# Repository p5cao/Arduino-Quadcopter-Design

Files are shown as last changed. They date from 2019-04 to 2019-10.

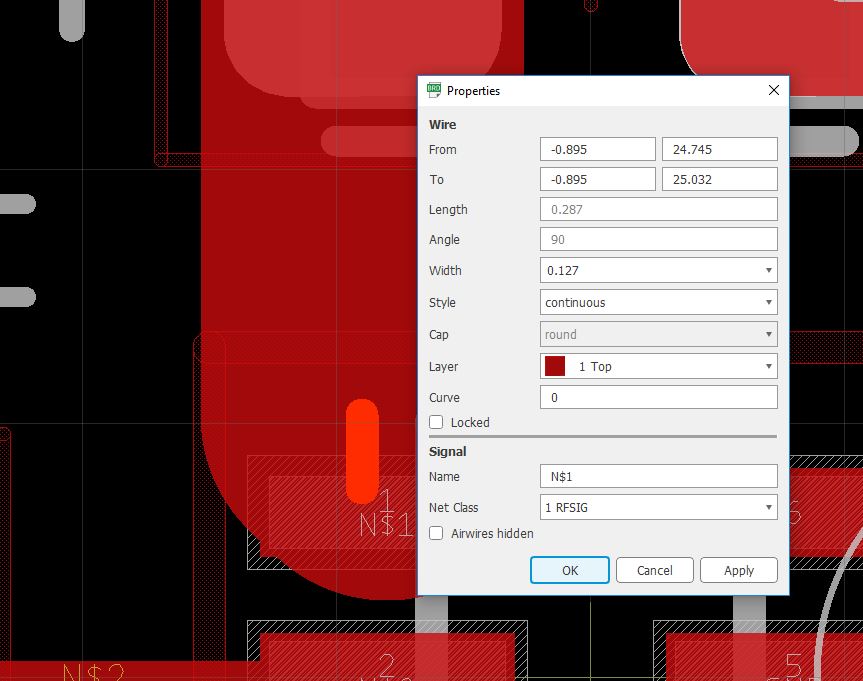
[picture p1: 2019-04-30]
hardware/N$1.JPG

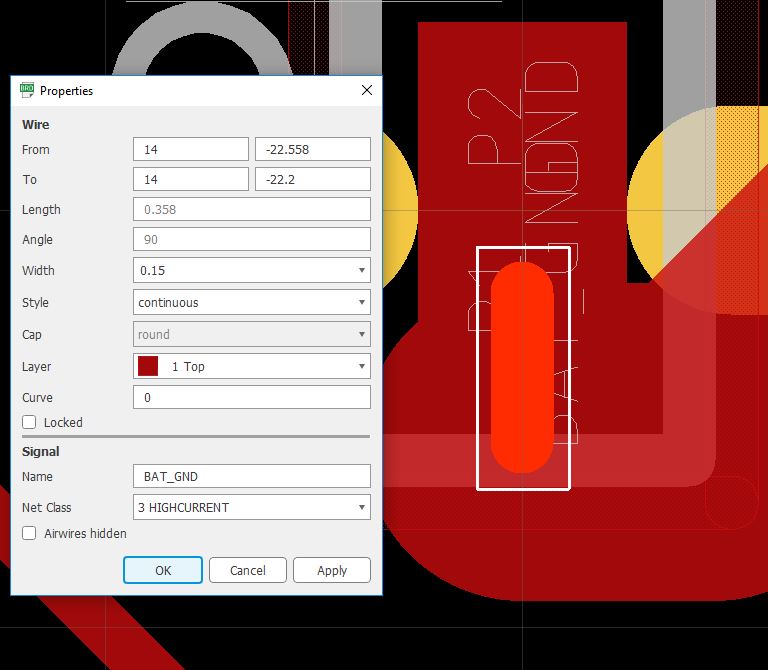
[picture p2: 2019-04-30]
hardware/bat_gnd.JPG

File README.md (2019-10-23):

# Arduino-Quadcopter-Design
A creative class project to design the PCB board for a quadcopter as well as programming the firmware and implementing the PID controller for flight controls.
The picture of our quadcopter can be found on this gallery webpage.
https://photos.google.com/share/AF1QipN9F1jDYG9cubRXA-CwWNmIePdVq3RI0pVtxd35Kb-5K7d3aRKYkmTJEXwJQgeCqA/photo/AF1QipMYG6V8wfTyHqf-2jjKtqaBbs2ouibxToXAU-El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

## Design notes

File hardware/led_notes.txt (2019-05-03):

CSE-276e 
Team KillersQuad
Members:Pengcheng Cao, Yangsheng Hu

OVERVIEW: 
18 LED lights in total will be used on the board -- 13 on the top and 5 on the bottom. Note that we are not including the two indicator LEDs (1 red and 1 green) near the MCU in this note.

---------------------------------------------------------------------------------------------------------------------------------------
Color        expected max current          forward voltages          max Supply voltages                   resistor values 
---------------------------------------------------------------------------------------------------------------------------------------
Red	25 mA			2 V		       4.2 V			88 Ohm (86.6 Ohm used)
---------------------------------------------------------------------------------------------------------------------------------------
Yellow 	25 mA			2 V		       4.2 V			88 Ohm (86.6 Ohm used)
---------------------------------------------------------------------------------------------------------------------------------------
Blue	25 mA			3.5 V	 	       4.2 V			28 Ohm
---------------------------------------------------------------------------------------------------------------------------------------

Trace width: 5mil (0.127 mm, same as our default trace setting) used.

%%%%%%%%%%%%%%%%%%%%%%%%%%%%%%%%%%%%%%%%%%%%%%%%%%%%%%%%%%%%%%%%%%%%%%%%%
%%%%%%%%%%%%%%%%%%%%%%%%%%%%%%%%%%%%%%%%%%%%%%%%%%%%%%%%%%%%%%%%%%%%%%%%%
DETAILS:

For width 0.127 mm (5 mil, same as our default trace setting), thickness 1 oz/ft^2, temperature 25 degrees Celcius, and length 100mm, the estimated trace resistance will be 0.382 Ohms, leading to a max voltage drop 0.382 Ohms*25 mA = 0.00955 V = 0.23% of the Voltage source. 
	Ref: http://circuitcalculator.com/wordpress/2006/01/24/trace-resistance-calculator

We are choosing the LTST-C170 series of LEDs emitting red, yellow, and blue lights manufactured by LITE-ON Technology Corporation. The red, yellow, and blue LEDs are of the MFR number LTST-C170KRKT, LTST-C170KSKT, and LTST-C170TBKT respectively.  The layout of LEDs ( for X-type rotor layout) will be as follows: 

*****************************************************************************************
--On the top:
4 blues on the top left arm ----------------------------------- 4 blues on the top right arm
1 yellow on the left front of the main board---------------N/A 
1 blue and 1 red on the bottom left arm ------------------- 1 yellow and 1 red on the bottom right arm
--On the bottom:
1 blue on the top left arm ------------------------------------- 1 blue on the top right arm
1 blue on the left middle of the main board -------------- N/A
1 yellow on the bottom left arm ----------------------------- 1 yellow on the bottom right arm
*****************************************************************************************  
Note: All the LEDs on the left will be driven by one MOSFET, and the ones on the right will be driven by another MOSFET.

Roughly speaking, we are using the red LEDs (warm color) as rear lights of our quad and the blue (cold color) indicating the foward direction.  LEDs will also be added on the left hand side of the main board to give a straightforward left direction.  The 5 LEDs on the bottom will tell the outline of our quad.

The LEDs on the left are connected to the PWM pin 9~ on the microcontroller (PB4 pin) via the mosfet from our custom library, which is the Si302CDS N-Channel 20V (D-S) mosfet provided by Vishay Siliconix. The LEDs on the right are connnected to the PWM pin 34~ on the microcontroller (PB6 pin) with a similar connection through another mosfet. We connect S-gate of the mosfet to pin 9~/34~ of the microcontroller, the G-gate to BAT_GND, and D-gate to all the parallel-connected LEDs. The total 18 LEDs will consume current of 450 mA, with 25 mA allocated to each to ensure at least 1.2 relative luminous intensity at high battery voltage(4.2V) and 0.9 relative luminous intensity at low battery voltage(3.7V). Each LED has a resistor serially connected to it to restrict the currents, and the power of LEDs is provided by V_BAT. We use the Ohm's law equation R = (V_source - V_LED)/I_LED to calculate the resistance required for choosing the resistors from DigiKey. 

The red and yellow LEDs have the maximum forward current (I_LED) of 25mA at maximum supply voltage (V_source) of 4.2V, which corresponds to 1.25 relative luminous intensity and the forward voltage (V_LED) of 2V. The anticipated serial resistor to be used here will be 88 Ohm. We are choosing the YAGEO RC0805FR-0786R6L resistor with 86.6 resistance to connect to the diode. We need in total 14 resistors of this type.

The Blue LEDs also have the maximum forward current of 25mA (mapped to 1.2 relative luminous intensity on the curve), with the correspondng forward voltage of 3.5V and maximum supply voltage(V_source) of 4.2V. So based on Ohms Law we need to connect the Blue LED with a serial resistor of 28 Ohm. We shall choose to use YAGEO RC0805FR-0728RL resistor with exactly 28 Ohm resistance. We need in total 4 resistors of this type. 

All the resistors are selected from the same series, Yageo RC, as the resistor in the custom library we built before, and also share the same mounting pad sizes and footprint.

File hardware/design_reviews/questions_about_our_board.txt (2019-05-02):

Reviewer Team Name: sudo_woodo
  
Devin Moore  djm016@ucsd.edu
  Brendon Chen brc019@ucsd.edu

Reviewee Team Name: killersquad
  
Pengcheng Cao p5cao@eng.ucsd.edu
  Yangsheng Hu  yah071@eng.ucsd.edu

Met: April 30, 2019 at ~12:00 PM PT

1. IMU Decoupling Capacitors

According to Prof. Swanson, "Ideally there should be no vias between a
   decoupling cap and the device." (See Piazza post @145)

Our answer: We have connected them directly without vias in between now.

2. Under the IMU, Layer 15

What is that yellow rectangle? Is it a trace? We are not sure.

Our answer: We have also built two cutouts within the IMU package, although we've already have the cutouts directly on the board. This will not hurt.

3. MCU Decoupling Capacitors

According to Prof. Swanson, "Ideally there should be no vias between a
   decoupling cap and the device." (See Piazza post @145)

Our answer: We have connected them directly without vias in between now.

4. There are name/value labels on vias throughout the board

For example, see R18, D14, D13, ...

Our answer: We have modified this problem.

5. LEDs

Traces N$37 and N$33 seem a bit sharp (e.g., 90 degree angles)

Our answer: We have rerouted our board based on a modified version and now no problems on this.

6. DRC

There are wire stubs that should be cleaned up (e.g., RES@3:GND)

Our answer: We have cleaned unnecssary wire stubs. Only two necessary ones are left (for antenna and NET_BRIDGE).

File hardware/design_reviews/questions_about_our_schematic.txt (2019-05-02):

Reviewer Team Name: sudo_woodo
  
Devin Moore  djm016@ucsd.edu
  Brendon Chen brc019@ucsd.edu

Reviewee Team Name: killersquad
  
Pengcheng Cao p5cao@eng.ucsd.edu
  Yangsheng Hu  yah071@eng.ucsd.edu

Met: April 30, 2019 at ~12:00 PM PT

1. LED Connections

The wires between LEDs and current limiting resistors are of class default.
   As a result, they are only 5 mil (0.127 mm) wide on the board. Is that
   alright since the trace sizes connecting the LED-resistor branches to VBAT
   and NMOSFETs are 30 mil? 

Our answer: that's a mistake, and we have corrected it.

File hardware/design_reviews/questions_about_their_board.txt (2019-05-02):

Reviews for the board design (Sudo_Wodoo)
--reviewed by Yangsheng Hu and Pengcheng Cao (2019/05/01)

Reviewer Team Name: killersquad
  
Pengcheng Cao p5cao@eng.ucsd.edu
  Yangsheng Hu  yah071@eng.ucsd.edu

Reviewee Team Name: sudo_woodo
  
Devin Moore  djm016@ucsd.edu
  Brendon Chen brc019@ucsd.edu

Met: April 30, 2019 at ~12:00 PM PT

Antenna and Antenna Driver:
1. The wire connection for the antenna is right. However, mayber it's better to do an mimic placement on the board as given in the repo. More specifically,  capacitor C1 can be moved to right up to the Balun.
2. I noticed that the pours are only covering the area below the capacitor C1. In fact, you can cover C1, too. Then, the GND pad on C1 could be connected to the GND plane directly through a via or so. 
3. Since we prefer to have nothing around the RF area, then we should be careful about the signals A7, A5, A3, which are pretty close to the balun in your design.

Power and Ground:
1. Some parts of the power/ground pours are very narrow (<0.5mm). Display each layer separately and pay attention to those parts with a cross shape, usually sitting in the throughhole. For example, if you check your throughhole GND of the IMU rescue header, and display only the ground plane layer 2, then you can see that cross parts are less than 0.5mm, which is roughly 0.3mm. This happens to be your PWR net class trace width. Probably this is a bug in autorouting such that some power/ground traces may finally be part of the power/ground pours during the final steps of the pour optimization. A possible solution: reduce the traces layout for power/ground signal; instead, use a via to directly push it into a power/gound plane. By doing this, the cross connection in the throughhole will be generated using the default thick metals.
2. For the Highcurrent net class, I think you've set your via diameters too small. The drill size should give an annular ring diameter of 30mil with annular ring to be 25% of drill radius. Your drill diameter should be no smaller than 24 mil.

IMU:
1. The capacitors are lying too close to each other, this would be hard for you to drop your parts on your board. In fact, not all the capacitors are important and sensitive. So, just make sure the sensitive ones are placed as near as possible. 
2. The position of the IMU header should be refined to make sure that the IMU on the breakout board(https://www.adafruit.com/product/3387) is roughly in the center. It seems like you can move the header a little bit to the right.

Microcontroller:
1. Similar to the IMU, the capacitors arel lying too close to each other. Professor suggests to allow 1-2mm between parts to make assembly easy.

Power Supply:
1. 3V3 plane power plane is not running underneath the voltage regulator U5. Thus, it will take some distance to go from your regulated 3V3 output to your other 3V3 parts.

Mechanical:
1. The arm length (from the center of DC motor to the edge of the board is about 31mm) is O.K. but maybe too short since the radius of the propeller is 55/2=27.5mm.  
2. The direction of the battery header B2 should be taken care of since it is facing the upper left propeller, which is pretty close (I did a basic calculation which is about 12mm). You will be struggling then when you get your battery wires in.
3. For the "cup" holder, the open angle is about 90 degree, which is fine, but can be smaller for better hold. Also, maybe it's better to give a little cut inside the motor holder circle to allow a bit stretching when you are squeezing in your motors.
4. Orienting all your parts in the same direction makes assembly easier (notice this on the FCB and your remote board).

LEDs:
1. The calculation is questionable (your final computed through current is said to be 3.94mA, however, this will lead to a different forward voltage again instead of the 2.0-2.1V, which is not matching). Since the through current depends on the forward voltage, the reasonable way is: first, set your expected through current and find the corresponding forward voltage; then, basing on your forward voltage and source voltage, calculate the remaining voltage the attached resistor should undertake; finally, you will have the value of the resistor based on the remaining voltage and through current.

Checks (DRC): 
1. Why did the error "clearance" at the Net Bridge 1 not resolved? Please explain
2. Why did width error of N$5 at pin 1 of balun 1 not resolved? Please explain
3. Why did width error of BAT_GND at Net Bridge 1 not resolved? Please explain

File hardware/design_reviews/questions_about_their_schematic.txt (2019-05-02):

Reviews for the Schematic drawing (Sudo_Wodoo)
-- reviewed by Yangsheng Hu and Pengcheng Cao (2019/05/01)

Reviewer Team Name: killersquad
  
Pengcheng Cao p5cao@eng.ucsd.edu
  Yangsheng Hu  yah071@eng.ucsd.edu

Reviewee Team Name: sudo_woodo
  
Devin Moore  djm016@ucsd.edu
  Brendon Chen brc019@ucsd.edu

Section I: Power supply

1. you should use the provided VBAT symbol instead of define a VBAT label on you net conected to enable pin.

2. try not to divide your schematic into too many components.

Section II: Headers

1. Think maybe you could specify your two headers by telling reader which one is IMU rescue or connects to signal pins.

2. Again you should try to symbols provided like VBAT, BAT_GND instead of defining labels.

Section III: LEDs

1. Your LED symbols may be too big, the professor has suggested to make the symbols no bigger than size of 0.4 x 0.2 inch, which produces inconsistency between professor's LED symbols and yours.  

Section IV: Motor Drivers

1. Think you should mark you Schottky diodes with a "Flyback" dashed box.

Section V: IMU

1. Your IMU symbol may be problematic. You should only place power pins at the top and ground pins at the bottom.  Dont treat C1 and CAP as Grounds they still have caps connected.

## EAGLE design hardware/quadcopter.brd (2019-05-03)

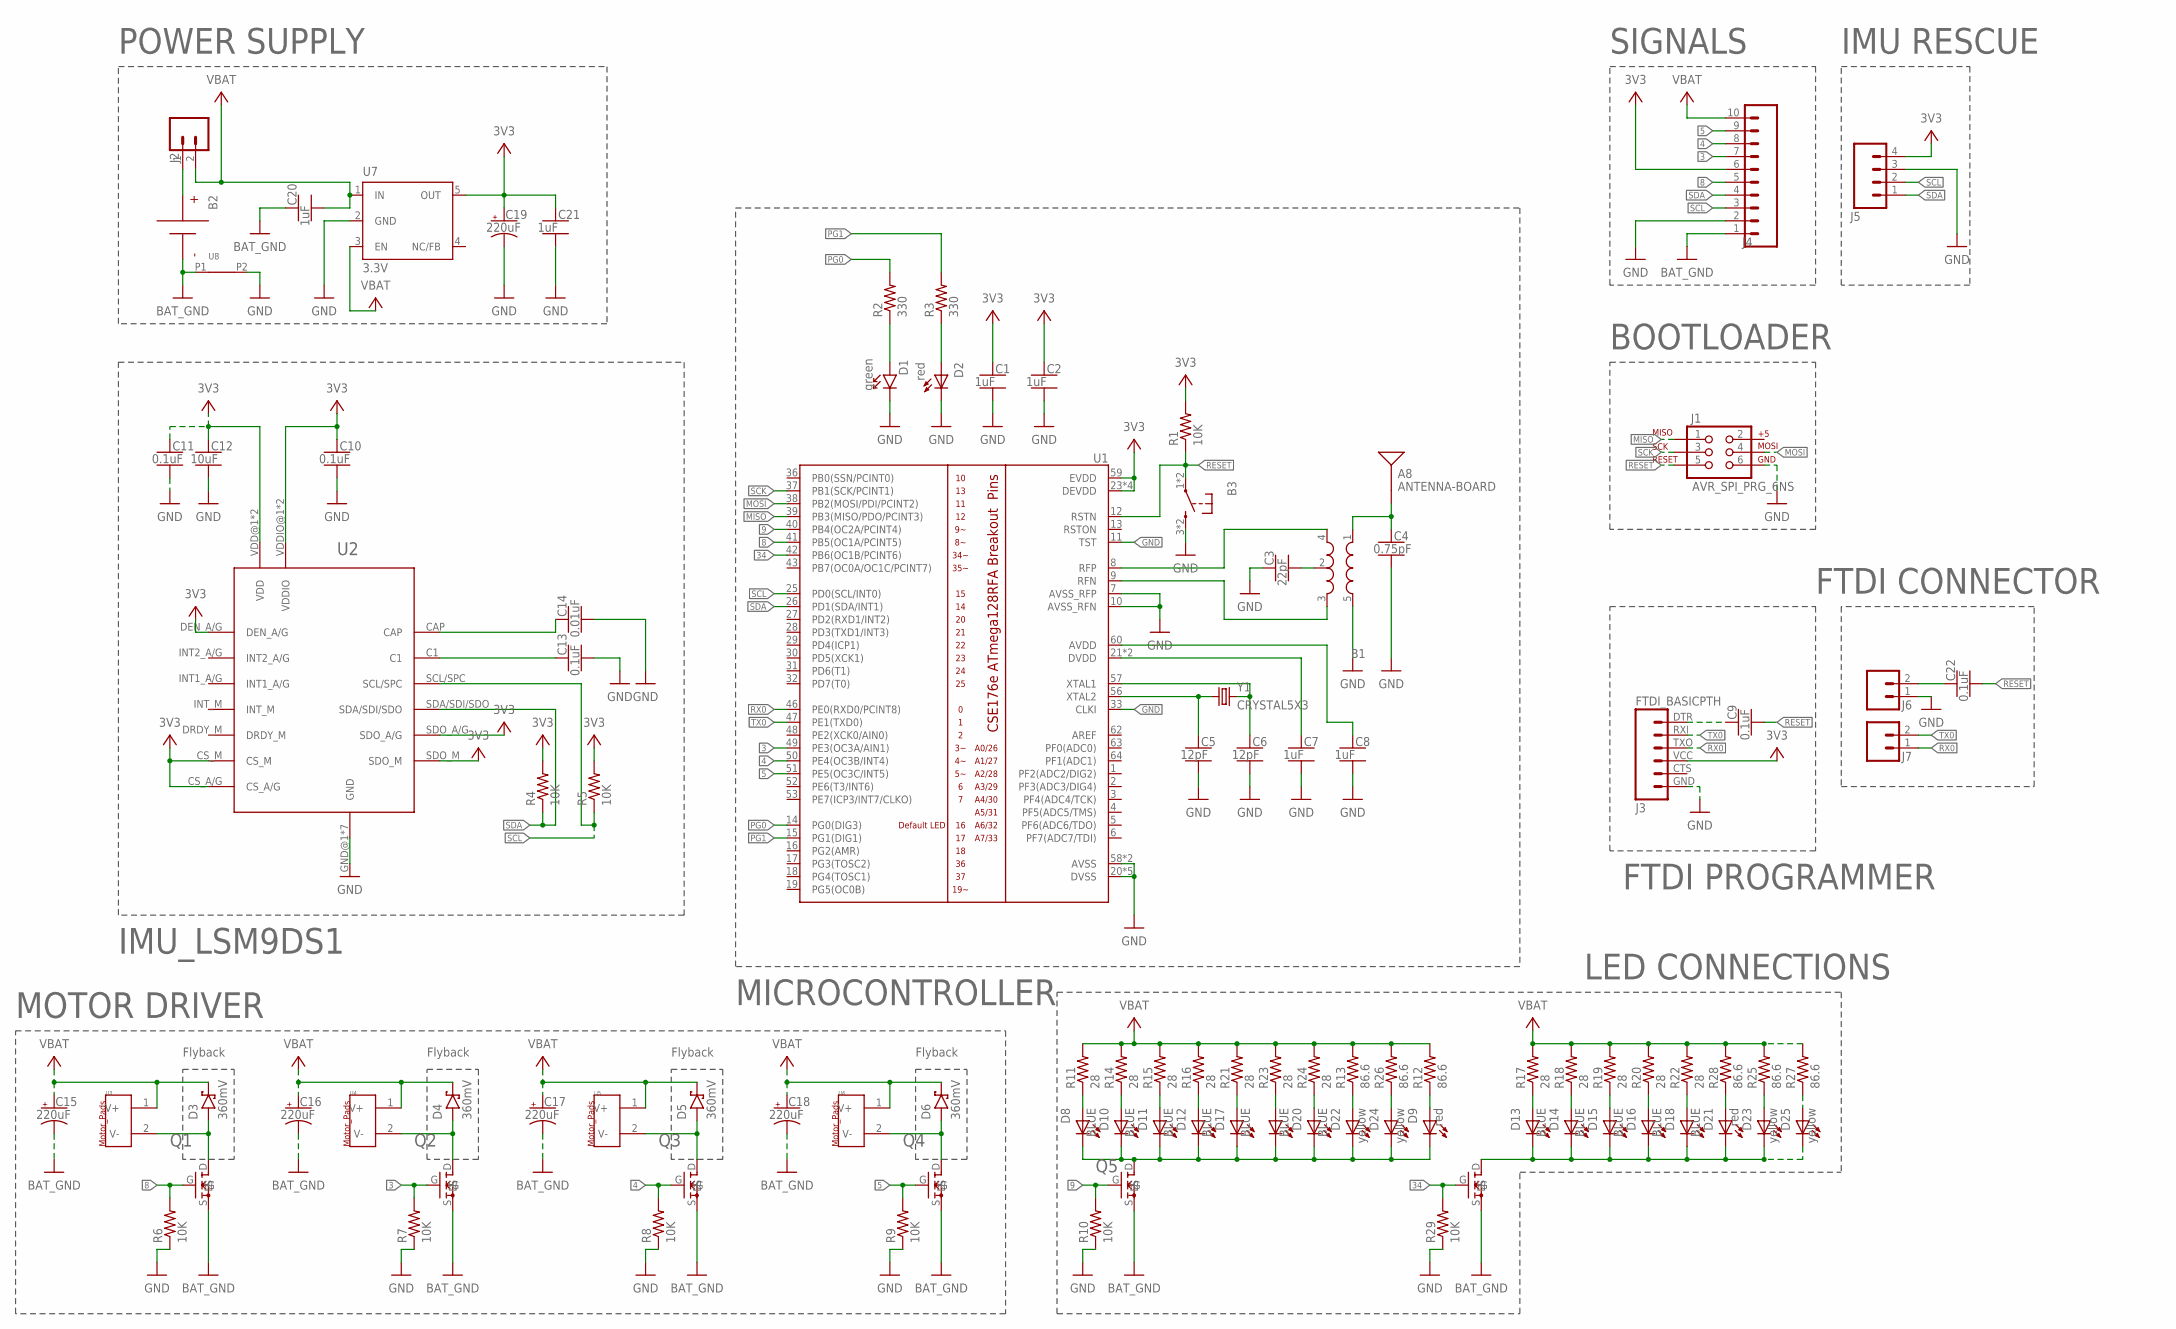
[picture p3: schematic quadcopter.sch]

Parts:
A8: ANTENNA-BOARD; ANT_PCB_2.4GHZ_NRF8001_1.6MM_1OZ
B1: BALUN0805; BALUN
B2: BATTERY-SCREW-TERMINAL; SCREW-TERMINAL-1X2-2.54MM
B3: PUSHBUTTON_-4.5X4.5; 4.5MM_TACTILE_SWITCH_TL3305AF160QG
C1, C2, C7, C8, C20, C21: 1uF; CAPC2012X140_HS
C3: 22pF; CAPC2012X140_HS
C4: 0.75pF; CAPC2012X140_HS
C5, C6: 12pF; CAPC2012X140_HS
C9, C10, C11, C13, C22: 0.1uF; CAPC2012X140_HS
C12: 10uF; CAPC2012X140_HS
C14: 0.01uF; CAPC2012X140_HS
C15, C16, C17, C18, C19: 220uF; CAPMP7343X310_HS
D1: green; LEDSC125X200X120-2_HS
D2: red; LED
D3, D4, D5, D6: 360mV; SOD3716X135_HS
D8, D10, D11, D12, D13, D14, D15, D16, D17, D18, D19, D20: BLUE; DIODE-LED-LTST-C170
D9, D21: red; DIODE-LED-LTST-C170
D22, D23, D24, D25: yellow; DIODE-LED-LTST-C170
J1: AVR_SPI_PRG_6NS; 2X3-NS
J2: HEADER-0.1IN-2POS-MALE; HDRV2W63P254_2X1_508X254H838_HS
J3: FTDI_BASICPTH; FTDI_BASIC
J4: HEADER-10POSTH-254X10; HDRV10W63P254_10X1_2540X254H838_HS
J5: HEADER-4POS-0.1IN-FEMALE; HDRVR4W80P254_1X4_1066X254X850B
J6, J7: HEADER-0.1IN-2POS-FEMALE; HDRV2W63P254_2X1_508X254H838_HS
Q1, Q2, Q3, Q4, Q5, Q6: MOSFET-VISHAY-SOT23-N-MOSFET; SOT-23_N_MOSFET
R1, R4, R5, R6, R7, R8, R9, R10, R29: 10K; RESC2012X60_HS
R2, R3: 330; RESC2012X60_HS
R11, R14, R15, R16, R17, R18, R19, R20, R21, R22, R23, R24: 28; RESC2012X60_HS
R12, R13, R25, R26, R27, R28: 86.6; RESC2012X60_HS
U1: ATMEGA128RFA1; QFN-64
U2: IMU_LSM-ST-LSM9DS1-IMU-LGA; LSM9DS1_IMU
U3, U4, U5, U6: MOTOR_PADS-MOLEX-0530470210; MOLEX-0530470210
U7: 3.3V; SOT23-DBV
U8: NET_BRIDGE-BRIDGE-SMD; NET_BRIDGE
Y1: CRYSTAL5X3; CRYSTAL-SMD-5X3

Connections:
3: J4.7, Q2.G, R7.2, U1.49 (PE3(OC3A/AIN1))
3V3: C1.1, C2.1, C10.1, C11.1, C12.1, C19.1 (+), C21.1, J3.VCC (4), J4.6, J5.4, R1.2, R4.2, R5.2, U1.23 (DEVDD), U1.34 (DEVDD), U1.44 (DEVDD), U1.54 (DEVDD), U1.59 (EVDD), U2.CS_A/G, U2.CS_M, U2.DEN_A/G, U2.SDO_A/G, U2.SDO_M, U2.VDD@1 (VDD), U2.VDD@2 (VDD), U2.VDDIO@1 (VDDIO), U2.VDDIO@2 (VDDIO), U7.5 (OUT)
4: J4.8, Q3.G, R8.2, U1.50 (PE4(OC3B/INT4))
5: J4.9, Q4.G, R9.2, U1.51 (PE5(OC3C/INT5))
8: J4.5, Q1.G, R6.2, U1.41 (PB5(OC1A/PCINT5))
9: Q5.G, R10.2, U1.40 (PB4(OC2A/PCINT4))
34: Q6.G, R29.2, U1.42 (PB6(OC1B/PCINT6))
BAT_GND: B2.1 (N), C15.2 (-), C16.2 (-), C17.2 (-), C18.2 (-), C20.1, J4.1, Q1.S, Q2.S, Q3.S, Q4.S, Q5.S, Q6.S, U8.P1
GND: B1.5 (GND), B3.3 (2), B3.4 (2), C1.2, C2.2, C3.1, C4.2, C5.2, C6.2, C7.2, C8.2, C10.2, C11.2, C12.2, C13.2, C14.2, C19.2 (-), C21.2, D1.C, D2.C, J1.6, J3.GND (6), J4.2, J5.3, J6.1, R6.1, R7.1, R8.1, R9.1, R10.1, R29.1, U1.7 (AVSS_RFP), U1.10 (AVSS_RFN), U1.11 (TST), U1.20 (DVSS), U1.24 (DVSS), U1.33 (CLKI), U1.35 (DVSS), U1.45 (DVSS), U1.55 (DVSS), U1.58 (AVSS), U1.61 (AVSS), U2.GND@1 (GND), U2.GND@2 (GND), U2.RES@1 (GND), U2.RES@2 (GND), U2.RES@3 (GND), U2.RES@4 (GND), U2.RES@5 (GND), U7.2 (GND), U8.P2
MISO: J1.1, U1.39 (PB3(MISO/PDO/PCINT3))
MOSI: J1.4, U1.38 (PB2(MOSI/PDI/PCINT2))
unnamed: A8.FEED, B1.1 (IN), C4.1
unnamed: B1.2 (GND), C3.2
unnamed: B1.4 (OUT1), U1.8 (RFP)
unnamed: B1.3 (OUT2), U1.9 (RFN)
unnamed: C5.1, U1.56 (XTAL2), Y1.1
unnamed: C6.1, U1.57 (XTAL1), Y1.3 (2)
unnamed: C7.1, U1.21 (DVDD), U1.22 (DVDD)
unnamed: C8.1, U1.60 (AVDD)
unnamed: D1.A, R2.1
unnamed: D2.A, R3.1
unnamed: C9.1, J3.DTR (1)
unnamed: C13.1, U2.C1
unnamed: C14.1, U2.CAP
unnamed: D3.A, Q1.D, U3.2 (V-)
unnamed: B2.2, J2.1
unnamed: D4.A, Q2.D, U4.2 (V-)
unnamed: D21.A, R28.1
unnamed: D5.A, Q3.D, U5.2 (V-)
unnamed: C22.1, J6.2
unnamed: D6.A, Q4.D, U6.2 (V-)
unnamed: D9.A, R12.1
unnamed: D24.A, R26.1
unnamed: D23.A, R25.1
unnamed: D22.A, R13.1
unnamed: D20.A, R24.1
unnamed: D19.A, R23.1
unnamed: D18.A, R22.1
unnamed: D17.A, R21.1
unnamed: D16.A, R20.1
unnamed: D15.A, R19.1
unnamed: D14.A, R18.1
unnamed: D13.A, R17.1
unnamed: D12.A, R16.1
unnamed: D11.A, R15.1
unnamed: D10.A, R14.1
unnamed: D8.A, R11.1
unnamed: D8.C, D9.C, D10.C, D11.C, D12.C, D17.C, D19.C, D20.C, D22.C, D24.C, Q5.D
unnamed: D13.C, D14.C, D15.C, D16.C, D18.C, D21.C, D23.C, D25.C, Q6.D
unnamed: D25.A, R27.1
PG0: R2.2, U1.14 (PG0(DIG3))
PG1: R3.2, U1.15 (PG1(DIG1))
RESET: B3.1, B3.2 (1), C9.2, C22.2, J1.5, R1.1, U1.12 (RSTN)
RX0: J3.TXO (3), J7.1, U1.46 (PE0(RXD0/PCINT8))
SCK: J1.3, U1.37 (PB1(SCK/PCINT1))
SCL: J4.3, J5.2, R5.1, U1.25 (PD0(SCL/INT0)), U2.SCL/SPC
SDA: J4.4, J5.1, R4.1, U1.26 (PD1(SDA/INT1)), U2.SDA/SDI/SDO
TX0: J3.RXI (2), J7.2, U1.47 (PE1(TXD0))
VBAT: C15.1 (+), C16.1 (+), C17.1 (+), C18.1 (+), C20.2, D3.C, D4.C, D5.C, D6.C, J2.2, J4.10, R11.2, R12.2, R13.2, R14.2, R15.2, R16.2, R17.2, R18.2, R19.2, R20.2, R21.2, R22.2, R23.2, R24.2, R25.2, R26.2, R27.2, R28.2, U3.1 (V+), U4.1 (V+), U5.1 (V+), U6.1 (V+), U7.1 (IN), U7.3 (EN)

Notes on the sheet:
MICROCONTROLLER
BOOTLOADER
FTDI PROGRAMMER
IMU_LSM9DS1
Flyback
MOTOR DRIVER
POWER SUPPLY
SIGNALS
IMU RESCUE
LED CONNECTIONS
FTDI CONNECTOR

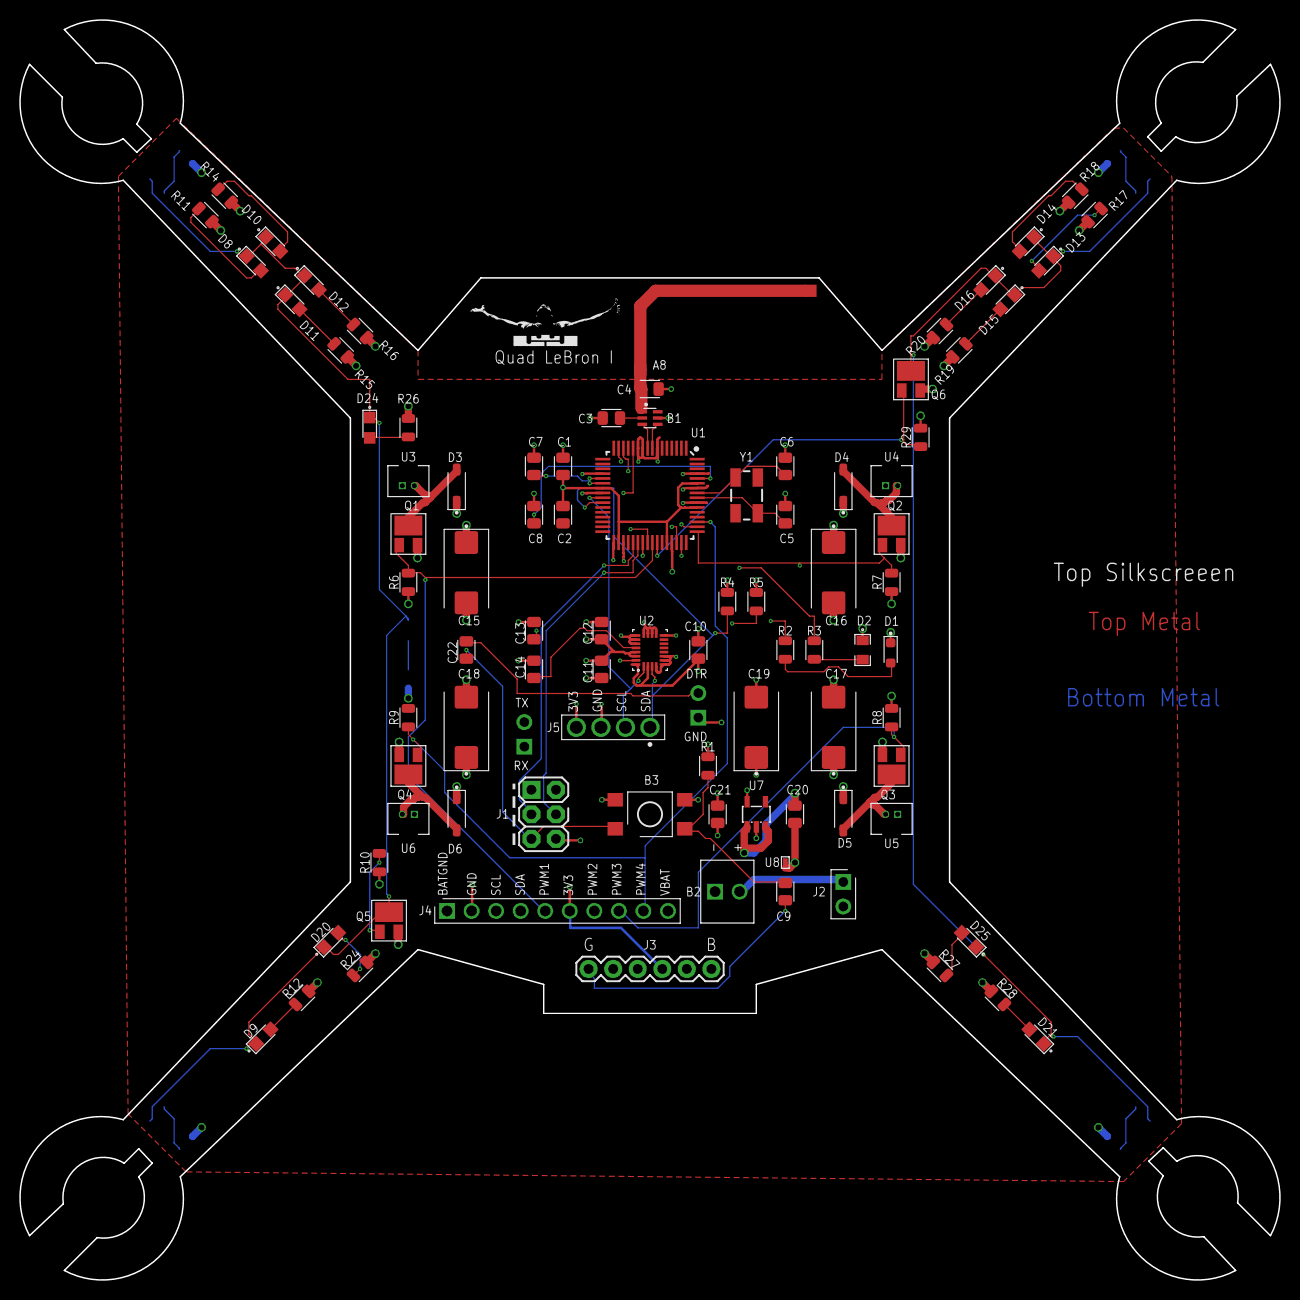
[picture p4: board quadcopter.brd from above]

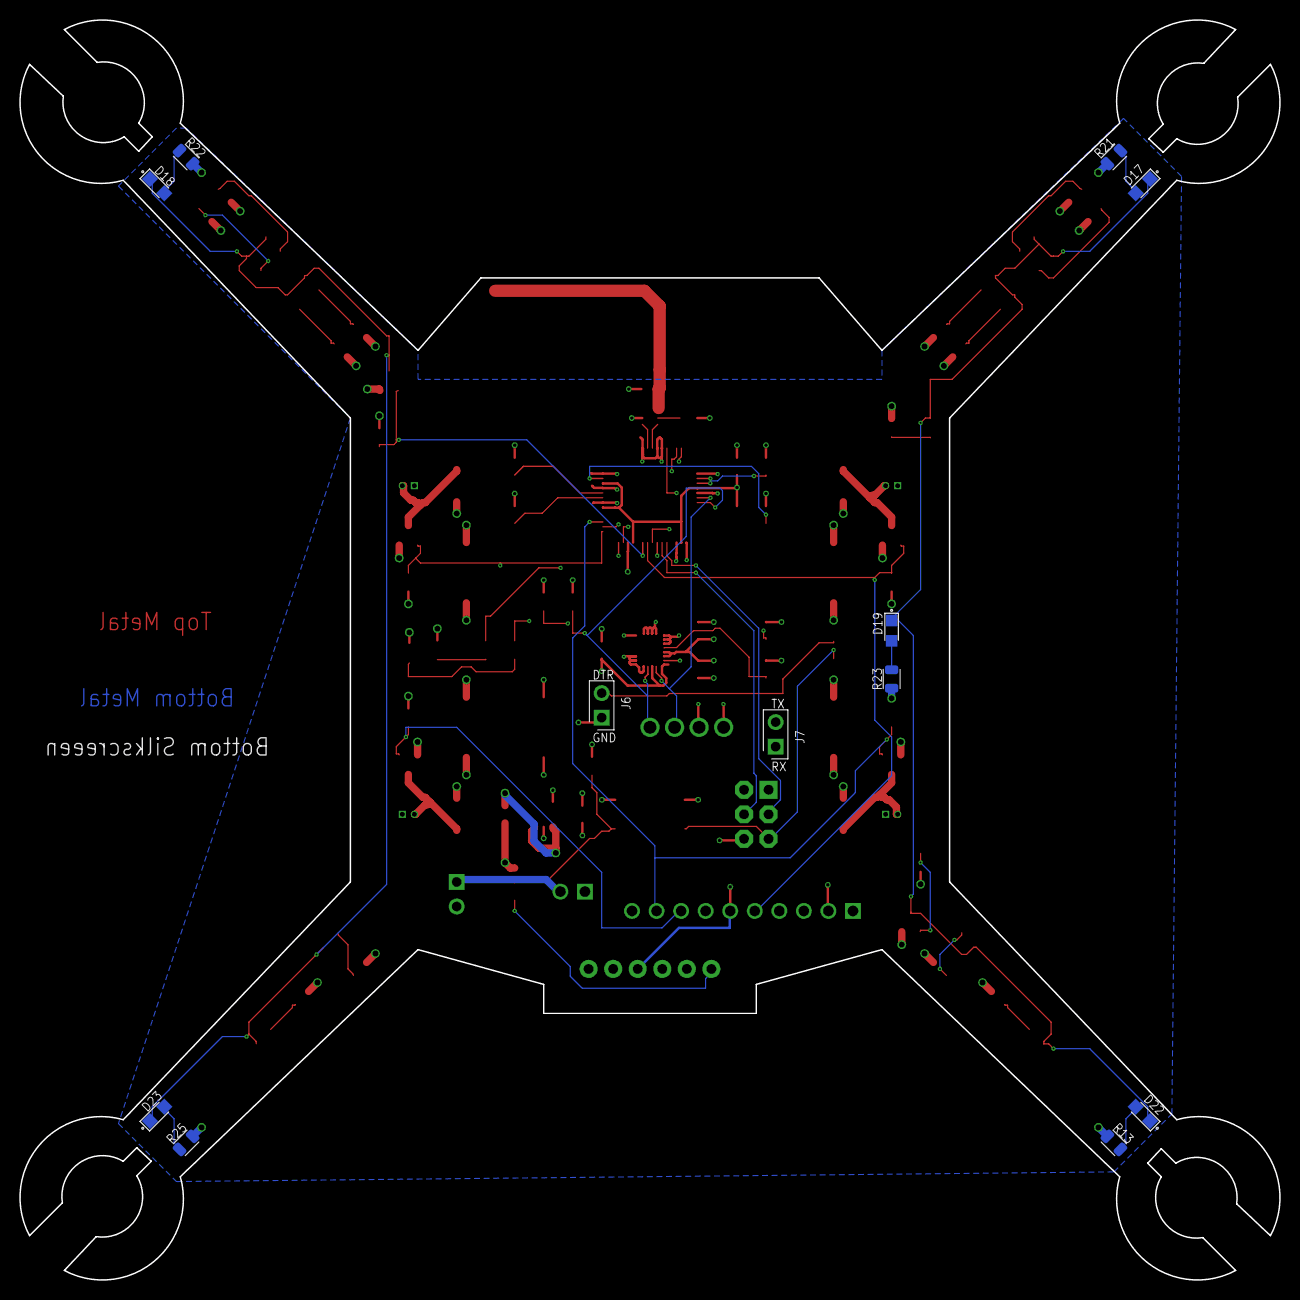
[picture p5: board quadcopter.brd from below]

Board: 4 copper layers, 130.4 x 130.4 mm, 103 parts (12 on the bottom side), 59 nets.

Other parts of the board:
U$1: LEBRON_JAMES
U$2: LAYER_LABELS

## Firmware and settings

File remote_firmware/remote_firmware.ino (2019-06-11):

#include <SPI.h>

// Remote control board 
// Note: Based on the version 4 from "Date: 15:13pm, May. 13th, 2019". Now, PID for all directions are added.
// by: Yangsheng Hu and Pengcheng Cao

// Remark: Two magic number used: magic-65 (replaced by 67): only receive reset info from FCB once starting from reset;
                               // magic-66: receive normal info
          // Note: Be careful about the magic number, the radio was disturbed by my home WIFI when I was using 65 with channel 11. 
          // It keeped giving me wrong info and reset my remote again and again. 

#include <quad_remote.h>
#include <radio.h>
#include <EEPROM.h>

#include <Adafruit_Simple_AHRS.h>

void readGimbal(int serialDisp); // for testing
int readGimbal_calibrated(int Value,int minVal, int maxVal);

void update_display();
void btn1_pressed(bool);
void btn2_pressed(bool);

void btn_left_pressed(bool down);
void btn_right_pressed(bool down);
void btn_center_pressed(bool down);
void knobs_update();
void knob_pressed(bool down);
void update_display_PID();


void arm_monitor(int gimbalYaw, int gimbalThrottle, int gimbalRoll, int gimbalPitch);// arm the board when conditions are satisfied

unsigned long startMillis;  //some global variables available anywhere in the program
unsigned long currentMillis;
const unsigned long period = 100;  //the value is a number of milliseconds

int disarm_mode = 1; // armed mode: arm = 0; disarmed mode (default): 1. Note: press BTN2 to disarm.
int calibrate_mode = 0; // uncalibrated mode (default): 0; calibrated mode: 1. Note: press BTN1 to change it
int counter_CalMode = 0; // Calbration procedures counter. 1,2:Yaw,3,4:Throttle,5,6:Roll,7,8:Pitch
int PID_mode = 0; // PID mode: online tuning = 1; offline = 0.
int P_I_D = 0; // Under PID_mode=1, PID gain: Kp: 0; Ki: 2; Kd: 1.



// all the info data sent on radio
struct Quad_Info{
  int magic; // symbol
  int gimbalYaw;
  int gimbalThrottle;
  int gimbalRoll;
  int gimbalPitch;
  int disarm_mode;
  float PID_Kp; //PID tuning parameters
  float PID_Ki;
  float PID_Kd;
  float filtered_pitch;
  float PID_output;
//  float PID_P;
//  float PID_D;
//  float PID_I;
  // quad_data_t orientation; // no need to send the IMU data in fact
};
Quad_Info measurements;

void setup() {
  // put your setup code here, to run once:
  const int SERIAL_BAUD = 19200; // Baud rate for serial port
  Serial.begin(SERIAL_BAUD); // Start up serial
  delay(100);

  quad_remote_setup(); //Should be put in the front(especially of radio setting), or it's not working.

  // The buttons and the knob trigger these call backs.       
  btn1_cb = btn1_pressed;
  btn2_cb = btn2_pressed;
  btn_left_cb =  btn_left_pressed;
  btn_right_cb = btn_right_pressed;
  btn_center_cb =  btn_center_pressed;
  knobs_update_cb = knobs_update; 
  knob1_btn_cb = knob_pressed;
  lcd.setBacklight(155,155,50);
  
  // *** set up the radio
  const int CHANNEL = 11; // radio channel number
  rfBegin(CHANNEL);// Initialize ATmega128RFA1 radio on channel (can be 11-26)
  // Send a message to other RF boards on this channel
  // rfPrint("ATmega128RFA1 Dev Board Online!\r\n");

  // *** set up the initial PID parameters
  measurements.PID_Kp = 0; // 0.55;
  measurements.PID_Kd = 0; // 0.2;
  measurements.PID_Ki = 0; //0.002;
  
  // *** set up the millis()
  startMillis = millis();  //initial start time
}



void loop() {
  // put your main code here, to run repeatedly:
  currentMillis = millis(); // current time

  // read the input values from gimbals
//  int gimbalYaw = analogRead(A0);
//  int gimbalThrottle = analogRead(A1);
//  int gimbalRoll = analogRead(A2);
//  int gimbalPitch = analogRead(A3);

  int minVal, maxVal;
  EEPROM.get(1,minVal); EEPROM.get(3,maxVal);
  // int gimbalYaw = readGimbal_calibrated(analogRead(A0), minVal, maxVal); //509~53
  int gimbalYaw = readGimbal_calibrated(analogRead(A0), 509, 53); //Not using calibration ones
//  int gimbalYaw1 = analogRead(A0);
//  Serial.print(gimbalYaw1); Serial.print(F("  "));
  
  EEPROM.get(5,minVal); EEPROM.get(7,maxVal);
  // int gimbalThrottle = readGimbal_calibrated(analogRead(A1), minVal, maxVal); // 70~514
  int gimbalThrottle = readGimbal_calibrated(analogRead(A1), 70, 514); //Not using calibration ones
//  int gimbalThrottle1 = analogRead(A1);
//  Serial.print(gimbalThrottle1); Serial.print(F("  ")); 
  
  EEPROM.get(9,minVal); EEPROM.get(11,maxVal);
  // int gimbalRoll = readGimbal_calibrated(analogRead(A2), minVal, maxVal); // 76~524
  int gimbalRoll = readGimbal_calibrated(analogRead(A2), 76, 524); //Not using calibration ones
//  int gimbalRoll1 = analogRead(A2);
//  Serial.print(gimbalRoll1); Serial.print(F("  "));

  EEPROM.get(13,minVal); EEPROM.get(15,maxVal);
  // int gimbalPitch = readGimbal_calibrated(analogRead(A3), minVal, maxVal); // 516~68
  int gimbalPitch = readGimbal_calibrated(analogRead(A3), 516, 68); //Not using calibration ones
//  int gimbalPitch1 = analogRead(A3);
//  Serial.print(gimbalPitch1); Serial.println(F("  "));

  arm_monitor(gimbalYaw, gimbalThrottle, gimbalRoll, gimbalPitch);
  
  // int serialDisp = 0;
  // readGimbal(serialDisp); // testing on the serial monitor

  // auxiliary display for calibration
  if (calibrate_mode & disarm_mode){
    if (counter_CalMode==1 || counter_CalMode==2){
            lcd.setCursor(11,1); lcd.print("     "); delay(200);
            lcd.setCursor(13,1); 
            lcd.print(gimbalYaw);          
    } else if (counter_CalMode==3 || counter_CalMode==4){
            lcd.setCursor(11,1); lcd.print("     "); delay(200);
            lcd.setCursor(13,1); 
            lcd.print(gimbalThrottle);     
    } else if (counter_CalMode==5 || counter_CalMode==6){
            lcd.setCursor(11,1); lcd.print("     "); delay(200);
            lcd.setCursor(13,1);  
            lcd.print(gimbalRoll);    
    } else if (counter_CalMode==7 || counter_CalMode==8){
            lcd.setCursor(11,1); lcd.print("     "); delay(200);
            lcd.setCursor(13,1); 
            lcd.print(gimbalPitch);   
    }
  }

  
  
  // Serial.println("Coming hehe");
  // Quad_Info measurements;
  measurements.magic = 66;
  measurements.gimbalYaw = gimbalYaw;
  measurements.gimbalThrottle = gimbalThrottle;
  measurements.gimbalRoll = gimbalRoll;
  measurements.gimbalPitch = gimbalPitch;
  measurements.disarm_mode = disarm_mode;
  // Serial.println(gimbalYaw);
  
  uint8_t b[sizeof(measurements)]; // a buffer to store the radio data
  int len = sizeof(measurements); // the length (number of characters)
    
  // send radio every period milliseconds (so that not too much radio)
  if (currentMillis - startMillis >= period){
    // send the radio of measurements data
    
    // Serial.print(len);
    memcpy(b, &measurements, len); // transform struct data into bytes and store it into the buffer 'b'
    // b[len] = 0;
    //Serial.print(sizeof(b));
    //****
    rfWrite(b,len); // ... send it out the radio
    
    //Serial.write((char*)b); //write
    //Serial.println(); delay(100);
  
    startMillis = currentMillis;  //IMPORTANT: update the clock counter 
  } 

  // read the radio if there is something
  if (len = rfAvailable())
  {
    // Serial.print(len);

    //*** Efficient way:
    // input data should not be read as a whole before the magic number is checked
    rfRead(b, 2); // Our magic number only take up 2 characters in the small-endian order such as: magic = b[1],b[0] = 00 66
    int magic_receive = b[0]; // small-endian order for each quantity, i.e., since int magic has two characters, then the lower digit character goes in first.
    // Serial.println(magic_receive);
    if (magic_receive==67){ // reset info from FCB
      rfRead(&b[2],len-2); // read the rest if the magic number is matching ours
      Quad_Info r_measurements_reset;
      memcpy(&r_measurements_reset,b,sizeof(r_measurements_reset)); // reconstruct the orignal 'struct' type data
      // Serial.write(r_measurements_reset.magic); // show the magic number in the serial port
      // Serial.print(sizeof(magic_receive));
      if (r_measurements_reset.magic==67){    // if the magic number is matching ours, then it is our data and should be processed
        // Serial.println((int)r_measurements_reset.disarm_mode);
        disarm_mode = r_measurements_reset.disarm_mode;
        if (disarm_mode==1){
          lcd.clear(); //lcd.home(); lcd.print("Disarmed Mode!");
        }
        delay(10);      
      }
    }else if (magic_receive==66) { // normal info from FCB
      rfRead(&b[2],len-2); // read the rest if the magic number is matching ours
      
      Quad_Info r_measurements;
      memcpy(&r_measurements,b,sizeof(r_measurements)); // reconstruct the orignal 'struct' type data
      // Serial.write(r_measurements.magic); // show the magic number in the serial port

      if (r_measurements.magic==66){    // if the magic number is matching ours, then it is our data and should be processed
        // Serial.println((int)r_measurements.disarm_mode);
        // Serial.println(r_measurements.orientation.roll);
        Serial.print(r_measurements.PID_output);
        Serial.print(F(" "));
        Serial.print(r_measurements.filtered_pitch);
//        Serial.print(F(" "));
//        Serial.print(r_measurements.PID_P);
//        Serial.print(F(" "));
//        Serial.print(r_measurements.PID_D);
//        Serial.print(F(" "));
//        Serial.print(r_measurements.PID_I);               
        Serial.println(F(" "));
        
        
        //*******do something then
        delay(10);      
      }
    }

    
    
  //***************************************
//    //*** Another way: read the whole data first. If the magic number is not matching ours, then ignore it.
//    rfRead(b, len); // read the data into the buffer
//    Quad_Info r_measurements;
//    memcpy(&r_measurements,b,sizeof(r_measurements)); // reconstruct the orignal 'struct' type data
//    // Serial.write(r_measurements.magic); // show the magic number in the serial port
//
//    if (r_measurements.magic==66){    // if the magic number is matching ours, then it is our data and should be processed
//      Serial.println((int)r_measurements.gimbalYaw);
//      delay(10);      
//    }
  //***************************************
  
  }
  
  // The following part is only excuted when typing something in the textbox of Serial Monitor
  if (len = Serial.available()){
    for (int i = 0; i<len; i++){
      b[i] = Serial.read(); //***repeting
    }
    rfWrite(b,len);// ... send it out the radio
  }

}


int readGimbal_calibrated(int Value,int minVal, int maxVal){
  // Note: Value--raw measured data; minVal,maxVal--the possible min and max measurements
  Value = map(Value,minVal,maxVal,0,255); // map to range [0,255]
  Value = constrain(Value,0,255); // a saturation constraint
  return Value;
}


// the following function is used for testing on the serial monitor
void readGimbal(int serialDisp){ 
  // read the input values from gimbals
  int gimbalYaw = analogRead(A0); // analog pin 0
  int gimbalThrottle = analogRead(A1); // analog pin 1
  int gimbalRoll = analogRead(A2); // analog pin 2
  int gimbalPitch = analogRead(A3); // analog pin 3

  // map the input values to the range 0~255
  gimbalYaw = map(gimbalYaw,509,53,0,255);
  gimbalThrottle = map(gimbalThrottle,70,516,0,255);
  gimbalRoll = map(gimbalRoll,76,524,0,255);
  gimbalPitch = map(gimbalPitch,518,68,0,255);

  // constrain the calibrated values within 0~255
  gimbalYaw = constrain(gimbalYaw,0,255);
  gimbalThrottle = constrain(gimbalThrottle,0,255);
  gimbalRoll = constrain(gimbalRoll,0,255);
  gimbalPitch = constrain(gimbalPitch,0,255);

  if (serialDisp){
    Serial.print("Yaw: ");
    Serial.print(gimbalYaw); Serial.print('\t');
    
    Serial.print("Throttle: ");
    Serial.print(gimbalThrottle); Serial.print('\t');
    
    Serial.print("Roll: ");
    Serial.print(gimbalRoll); Serial.print('\t');
    
    Serial.print("Pitch: ");
    Serial.println(gimbalPitch); // Starting from another line after printing
    delay(1); // delay in between reads for stability    
  }
}


void update_display(){
    if (calibrate_mode & disarm_mode){
      counter_CalMode = counter_CalMode+1;
      switch (counter_CalMode) {
        case 1: // calibrate the Yaw
          lcd.setCursor(0, 0);
          lcd.print("Yaw2leftmost");
          lcd.setCursor(0,1);
          lcd.print("hit CENTER "); break;
        case 2: // calibrate the Yaw
          EEPROM.update(1,analogRead(A0));
          lcd.setCursor(0, 0);
          lcd.print("Yaw2rightmost");
          lcd.setCursor(0,1);
          lcd.print("hit CENTER "); break;
        case 3: // calibrate the Throttle
          EEPROM.update(3,analogRead(A0));
          lcd.setCursor(0, 0);
          lcd.print("Throttle2lowest");
          lcd.setCursor(0,1);
          lcd.print("hit CENTER "); break;  
        case 4: // calibrate the Throttle
          EEPROM.update(5,analogRead(A1));
          lcd.setCursor(0, 0);
          lcd.print("Throttle2highest");
          lcd.setCursor(0,1);
          lcd.print("hit CENTER "); break;         
        case 5: // calibrate the Roll
          EEPROM.update(7,analogRead(A1));
          lcd.setCursor(0, 0);
          lcd.print("Roll2leftmost");
          lcd.setCursor(0,1);
          lcd.print("hit CENTER "); break;
        case 6: // calibrate the Roll
          EEPROM.update(9,analogRead(A2));
          lcd.setCursor(0, 0);
          lcd.print("Roll2rightmost");
          lcd.setCursor(0,1);
          lcd.print("hit CENTER "); break;
        case 7: // calibrate the Pitch
          EEPROM.update(11,analogRead(A2));
          lcd.setCursor(0, 0);
          lcd.print("Pitch2lowest");
          lcd.setCursor(0,1);
          lcd.print("hit CENTER "); break;
        case 8: // calibrate the Pitch
          EEPROM.update(13,analogRead(A3));
          lcd.setCursor(0, 0);
          lcd.print("Pitch2highest");
          lcd.setCursor(0,1);
          lcd.print("hit CENTER ");
          break; 
        default: //reset
          EEPROM.update(15,analogRead(A3));
          counter_CalMode = 0; calibrate_mode = 0;//reset
      }      
    }
}

void btn1_pressed(bool down) {
  if(down) {
    // Serial.println("btn1 down");
    calibrate_mode = (calibrate_mode+1)%2;
    counter_CalMode = 0; // reset from the first mode to tune
    if (calibrate_mode & disarm_mode){
      lcd.clear();
      lcd.setCursor(0, 0);
      lcd.print("Calibration ON");  
      lcd.setCursor(0,1); 
      lcd.print("Press btnCENTER");
    } 
  } else {
    // Serial.println("btn1 up");    
  }
}

void btn2_pressed(bool down) {
  if(down) {
    // Serial.println("btn2 down");
    disarm_mode = 1; // disarm both the remote and quad boards.
    PID_mode = 0; // PID mode offline
    lcd.noBlink();
    lcd.clear(); // lcd.home(); lcd.print("Disarmed Mode!");
  }else {
    Serial.println("btn2 up");    
  }
}
   
void btn_center_pressed(bool down) {
  if(down) {
    // Serial.println("center down");
    // update_display();
    lcd.clear(); delay(100);
    update_display();
  } else {
    Serial.println("center up");    
  }
}

void arm_monitor(int gimbalYaw, int gimbalThrottle, int gimbalRoll, int gimbalPitch){
  if (calibrate_mode==0){ // only able to arm when not calibrating
    if (gimbalYaw<=3 && gimbalThrottle<=3 && gimbalRoll>=252 && gimbalPitch<=3){
      disarm_mode = 0; // turn into armed mode
      lcd.clear(); lcd.home(); lcd.print("Armed Mode!");
    }  
  }
}

void update_display_PID(){
  if(P_I_D==0){// tuning Kp
        lcd.setCursor(0,1); lcd.print("    "); delay(50); // remove unused digits when the number of significant digits change 
        lcd.setCursor(0,1); lcd.print("P"); delay(50); lcd.print((int)(measurements.PID_Kp*1000)); 
        knob1.setCurrentPos((int)(measurements.PID_Kp*1000/20)); // resolution is 0.02
      }else if(P_I_D==1){// tuning Kd
        lcd.setCursor(5,1); lcd.print("    "); delay(50); // remove unused digits when the number of significant digits change
        lcd.setCursor(5,1); lcd.print("D"); delay(50); lcd.print((int)(measurements.PID_Kd*1000)); 
        knob1.setCurrentPos((int)(measurements.PID_Kd*1000/20));
      }else{
        lcd.setCursor(10,1); lcd.print("    "); delay(50); // remove unused digits when the number of significant digits change
        lcd.setCursor(10,1); lcd.print("I"); delay(50); lcd.print((int)(measurements.PID_Ki*1000)); 
        knob1.setCurrentPos((int)(measurements.PID_Ki*1000/10)); // resolution is 0.01
      }
}


void btn_left_pressed(bool down) {
  if(down) {
    // Serial.println("left down");
    if(PID_mode==1 && disarm_mode==0){
      P_I_D = (P_I_D-1)%3;
      update_display_PID();
    }
  } else {
    // Serial.println("left up");
  }
}

void btn_right_pressed(bool down) {
  if(down) {
    // Serial.println("right down");
    if(PID_mode==1 && disarm_mode==0){
      P_I_D = (P_I_D+1)%3;
      update_display_PID();
    }
  } else {
    // Serial.println("right up");    
  }
}

void knobs_update() { // the code for knobs and buttons should be as short as possible
  // Serial.print("Knob: ");
  // Serial.println(knob1.getCurrentPos());
  if(PID_mode==1 && disarm_mode==0){ //PID online tuning mode is on under arm mode
    if(P_I_D == 0){ // the operating code should be moved to the loop(){}
      measurements.PID_Kp = (float)knob1.getCurrentPos()*20/1000; // resolution is 0.02
    }else if(P_I_D == 1){
      measurements.PID_Kd = (float)knob1.getCurrentPos()*20/1000;
    }else if(P_I_D == 2){
      measurements.PID_Ki = (float)knob1.getCurrentPos()*10/1000; // resolution is 0.01
    }
    update_display_PID(); 
  }
}

void knob_pressed(bool down) {
  if(down) {
    // Serial.println("knob down");
    // knob1.setCurrentPos(0); // No need to reset the PID value to zero, which is also dagerous.
    PID_mode = (PID_mode+1)%2; 
    P_I_D = 0; knob1.setCurrentPos((int)(measurements.PID_Kp*1000/20)); // this initialization is important, or your quad will blow up.
    if(PID_mode==1 && disarm_mode==0){
      lcd.clear(); lcd.home(); lcd.print("PID Mode!(10e-3)"); lcd.blink();
    }else{
      lcd.clear(); P_I_D = 0; lcd.noBlink();
      lcd.home(); 
      if(disarm_mode==0){
        lcd.print("Armed Mode!"); // Still armed mode!! 
      }
      
    }
  }else {
    // Serial.println("knob up");    
  }
}

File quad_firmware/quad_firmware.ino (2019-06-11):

// Quad board 
// Note: Based on the version 4 from "Date: 15:13pm, May. 13th, 2019". Now, PID for all directions are added.
// by: Yangsheng Hu and Pengcheng Cao

// Remark: 1. Although Baud rate 115200 (the highest the best in principle) is OK for Example code "ahrs_quad.ino", we 
//         could only work with up to 19200 when we incorporate IMU measurements into the total code.
//         2. Make sure everytime you are using 'sec'. Note that the unit for millis() is 'msec'. So remember to divide it by 1000.
//         3. (int) 20ms/1000 = 0 sec. So you should use float type for the time keeper.
//         4. Be careful about the radio channel and magic number. My home WIFI disturb my radio with magic 65 and channel 11.
//         5. One motor device (NO.1) seems not working in the same way as others and has been replaced
#include "radio.h"

#include <Wire.h>
#include <Adafruit_Sensor.h>
#include <Adafruit_LSM9DS1.h>
#include <Adafruit_Simple_AHRS.h>

// Create LSM9DS0 board instance.
Adafruit_LSM9DS1 lsm = Adafruit_LSM9DS1();
// Create simple AHRS algorithm using the LSM9DS0 instance's accelerometer and magnetometer.
Adafruit_Simple_AHRS ahrs(&lsm.getAccel(), &lsm.getMag(), &lsm.getGyro());

#define FDS_MODE B00000100 // For setting register CTRL_REG7_XL: data sent to output register and FIFO; 
                          // No need for FDS_MODE here since Table.70 in the datasheet is not right. Fig.8 is right.

void setupSensor()
{
  // Instruction: high pass filter with GYPO (since biased) and low pass filter with Accelerometer (since noisy).
  // Set data rate for G and XL.  Set G low-pass cut off.  (Section 7.12)
  // Note: ODR_50 is not accurately 50Hz. The datasheet gives 59.5Hz. 
  //       However, 238hz ODR is used (o.k. as long as higher than 1/(now-last)sec). Higher one will make settings like ODR ratio more flexible.
  lsm.write8(XGTYPE, Adafruit_LSM9DS1::LSM9DS1_REGISTER_CTRL_REG1_G,  ODR_238 | G_BW_G_01 );  //238hz ODR + 76 Hz LPF1 cutoff. 29hz LPF2 cutoff if enabled.

  // Set low-pass and high-pass G filter frequency divider (Section 7.13-7.14)
  // --Approach 1: On Fig.28, the signal goes through HPF without LPF2
//  lsm.write8(XGTYPE, Adafruit_LSM9DS1::LSM9DS1_REGISTER_CTRL_REG2_G, G_OUTSEL_HP); // path through HPF without LPF2
//  lsm.write8(XGTYPE, Adafruit_LSM9DS1::LSM9DS1_REGISTER_CTRL_REG3_G, G_HP_CUT_0010); // enable HPF + 4 Hz cutoff (for ODR=238hz). No need to set G_HP_EN since LPF2 is not used.
    // --Approach 2: On Fig.28, the signal goes through HPF and then LPF2(filter high freq noise caused by HPF)
  lsm.write8(XGTYPE, Adafruit_LSM9DS1::LSM9DS1_REGISTER_CTRL_REG2_G, G_OUTSEL_HP_LP); // path through HPF and LPF2
  lsm.write8(XGTYPE, Adafruit_LSM9DS1::LSM9DS1_REGISTER_CTRL_REG3_G, G_HP_EN | G_HP_CUT_0101); // enable HPF + 0.5 Hz cutoff (for ODR=238hz). Followed by LPF2 with 29Hz cutoff.
 
 
  // Enable the XL (Section 7.23)
  lsm.write8(XGTYPE, Adafruit_LSM9DS1::LSM9DS1_REGISTER_CTRL_REG5_XL, XL_ENABLE_X | XL_ENABLE_Y | XL_ENABLE_Z);

  // Set low-pass XL filter frequency divider (Section 7.25)
  // Note: FDS_MODE not needed since the datasheet there is wrong. Fig.8 and Table.70(wrong) contradicts.
  lsm.write8(XGTYPE, Adafruit_LSM9DS1::LSM9DS1_REGISTER_CTRL_REG7_XL, HR_MODE | XL_LP_ODR_RATIO_9); // data sent to output register and FIFO. XL LPF2 cutoff freq = ODR/9
  
  // enable mag continuous (Section 8.7)
  lsm.write8(MAGTYPE, Adafruit_LSM9DS1::LSM9DS1_REGISTER_CTRL_REG3_M, B00000000); // continuous mode

  // This only sets range of measurable values for each sensor.  Setting these manually (I.e., without using these functions) will cause incorrect output from the library.
  lsm.setupAccel(Adafruit_LSM9DS1::LSM9DS1_ACCELRANGE_2G);
  lsm.setupMag(Adafruit_LSM9DS1::LSM9DS1_MAGGAIN_4GAUSS);
  lsm.setupGyro(Adafruit_LSM9DS1::LSM9DS1_GYROSCALE_500DPS); // could be used to change the range of gyro values (set the max change rate)
}



void driveMotors(int motorN,int dutyCycle);
float complementaryFilter(float angle_m, float velocity_m, float last_angle, float delta_t, float gain);

int disarm_mode = 1; // armed mode: arm = 0; disarmed mode (default): 1. Note: press BTN2 to disarm. 
int dutyCycle = 0; // for PWM input of four motors. Lowest(0, default)

unsigned long startMillis; // time counter
unsigned long last_radio = millis(); // sending radio not that fast, e.g. every period millisecs
const unsigned long period = 100;  //the value is a number of milliseconds
float last = millis(); // the last time mark point for the IMU sampling
                // Note: we should use float type if we are using 'sec' unit, since (int) 20 msec/1000 = 0 sec


float roll_rate_regression[3];
float filtered_pitch = 0; // using complementary filter
float filtered_pitch_last = 0;
float filtered_pitch_sum = 0; // for integral of PID
float filtered_pitch_df = 0;  // for derivative of PID
float filtered_pitch_df_1 = 0; // the value from last time instant (for filtering design)
float ref_pitch = 0; // reference signal from the remote gimbal
float err_pitch = 0; // tracking error
float err_pitch_last = 0;
float alpha=0; // Integration saturation. alpha=0 no integration; alpha=1 with integration.
float beta=0; // Changing the integration rate. 0: no integration; 1: the fastest.


float filtered_roll = 0; // using complementary filter
float filtered_roll_last = 0;
float filtered_roll_sum = 0; // for integral of PID
float filtered_roll_df = 0;
float filtered_roll_df_1 = 0;
float ref_roll = 0; // reference signal from the remote gimbal
float err_roll = 0; // tracking error
float err_roll_last = 0;
float alpha_roll = 0;
float beta_roll = 0;


float filtered_yaw = 0; // using complementary filter
float filtered_yaw_last = 0;
float filtered_yaw_sum = 0; // for integral of PID
float ref_yaw = 0; // reference signal from the remote gimbal
float err_yaw = 0; // tracking error
float err_yaw_last = 0;
float alpha_yaw = 0;
float gamma_yaw = 0; // scaling for Kp


float PID_output; // The output of PID controller for pitch
float PID_output_1=0; // The PID output from last time instant (for 1st order LP filter design)

float PID_output_roll;
float PID_output_yaw;

// all the info data sent on radio
struct Quad_Info{
  int magic; // symbol
  int gimbalYaw;
  int gimbalThrottle;
  int gimbalRoll;
  int gimbalPitch;
  int disarm_mode;
  float PID_Kp; //PID tuning parameters
  float PID_Ki;
  float PID_Kd;
  float filtered_pitch;
  float PID_output;
//  float PID_P;
//  float PID_D;
//  float PID_I;
  // quad_data_t orientation; // no need to send IMU data in fact
};

Quad_Info from_remote; // used to receive data from the remote board
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
